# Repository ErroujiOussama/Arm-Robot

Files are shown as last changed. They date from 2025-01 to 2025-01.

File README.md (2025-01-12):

# Arm-Robot

## 3D Model

## Kinematics

## Hardaware

## Simulation 

### 1. PyBullet Robot Simulation

#### Overview
This Project provides a simulation setup using PyBullet to load and control a robot model.

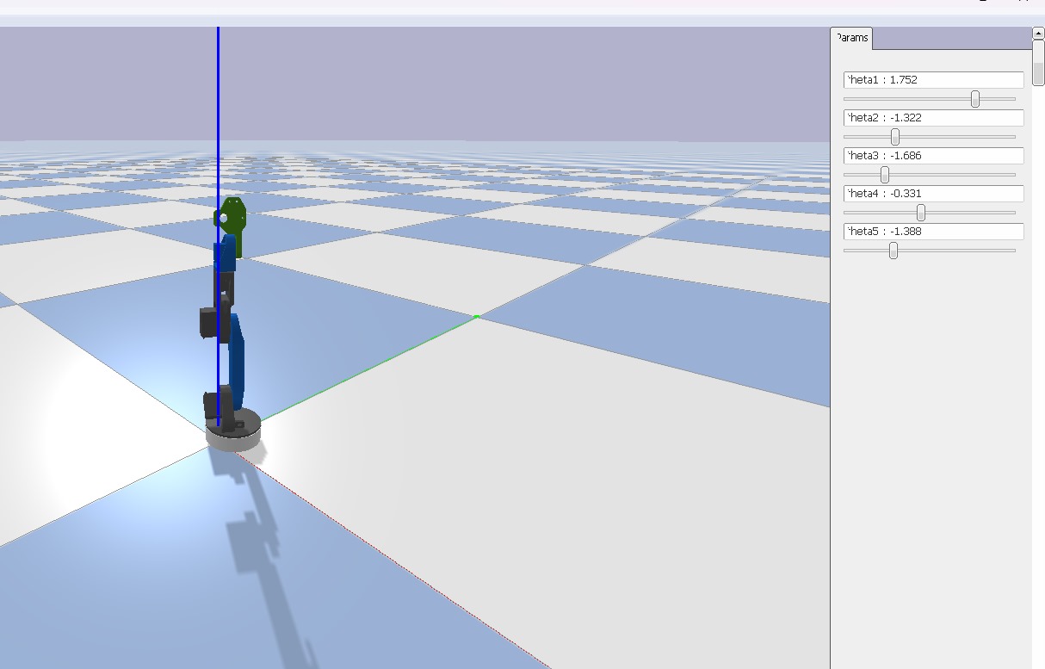
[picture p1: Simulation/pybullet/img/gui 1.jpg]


#### Features
- **Gravity and Physics Setup**: Configures gravity in the simulation.
- **Joint Control**: Creates sliders for each robot joint to control their positions interactively.

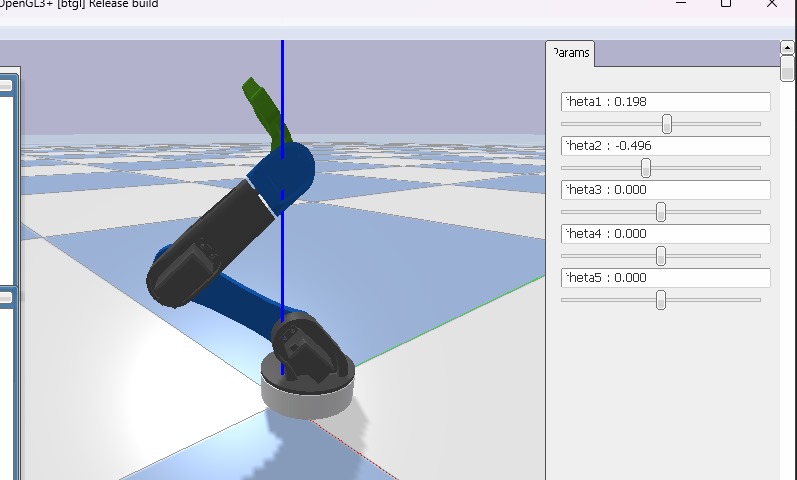
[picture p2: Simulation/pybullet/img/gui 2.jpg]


- **Collision Detection**: Detects and logs collisions between the robot's links and other objects in the environment.

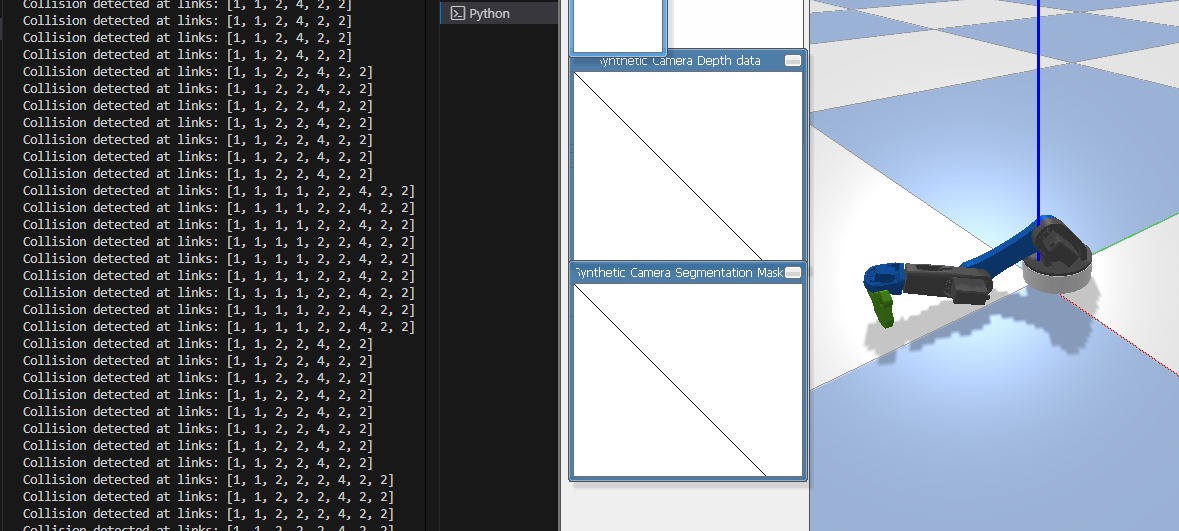
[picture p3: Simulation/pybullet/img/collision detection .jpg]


#### Notes
- The simulation runs at 240 Hz by default.

### 2. Roboticstoolbox (python)

This code combines simulation, kinematics, and control to visualize the motion of a robot arm.
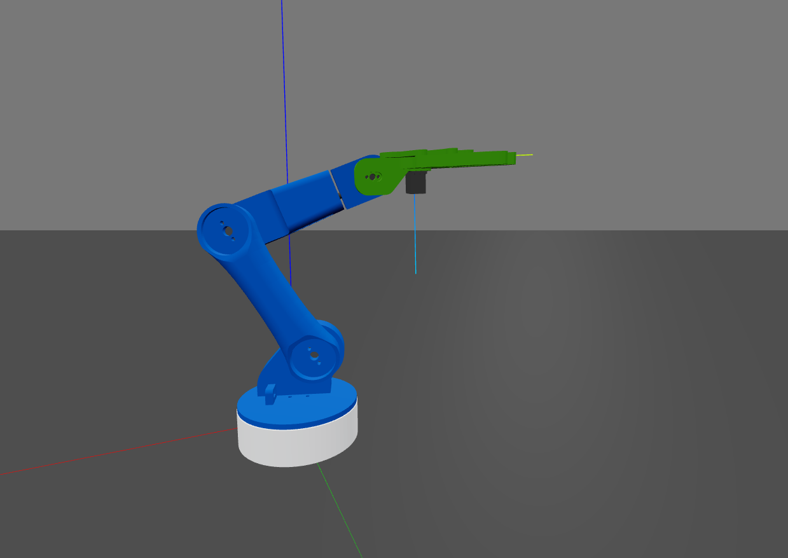
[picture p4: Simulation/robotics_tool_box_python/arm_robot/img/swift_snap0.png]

#### **Libraries and Tools**
- roboticstoolbox: Used for modeling and controlling robots.
- swift: Provides a 3D visualization interface for robotics simulation.
- spatialmath: Handles transformations like rotations and translations.
- spatialgeometry: Adds geometric primitives for visualization.

#### **Functions**
- move_to_position:
Moves the robot's end-effector to a target position using servoing.
Computes joint velocities using the Jacobian and pseudoinverse.

#### **Execution**
Sequential movements along the x, y, and z axes demonstrate the robot’s capability.

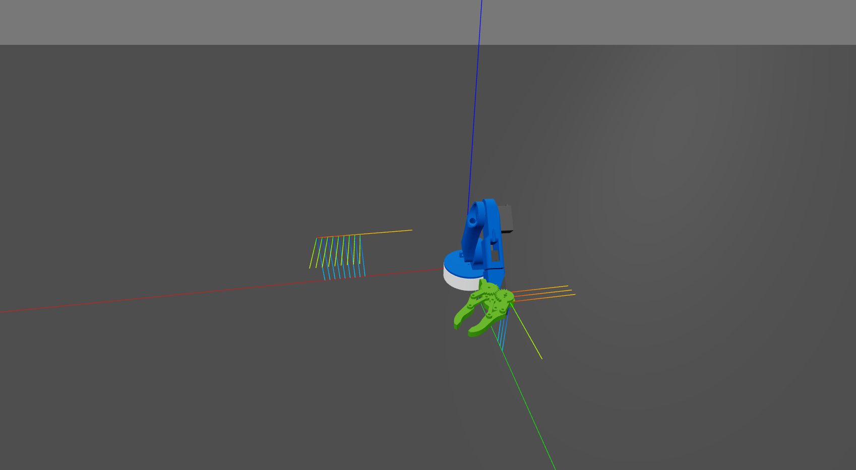
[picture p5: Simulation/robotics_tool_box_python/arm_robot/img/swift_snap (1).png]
 

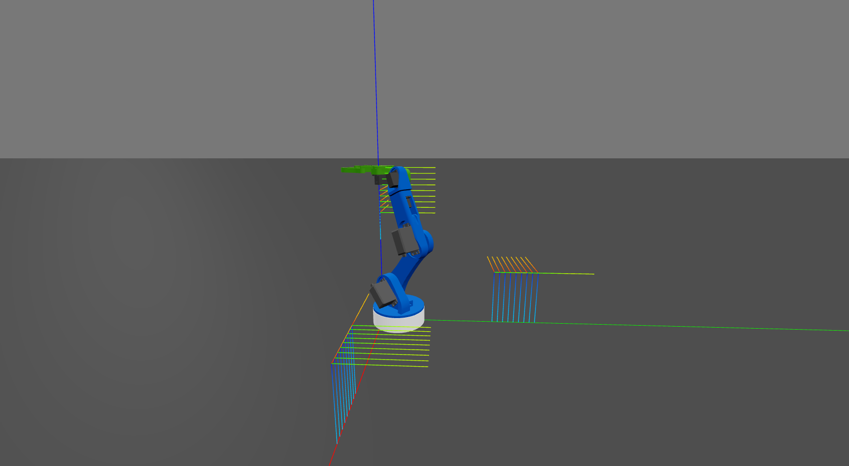
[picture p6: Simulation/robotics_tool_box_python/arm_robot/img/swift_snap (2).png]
 

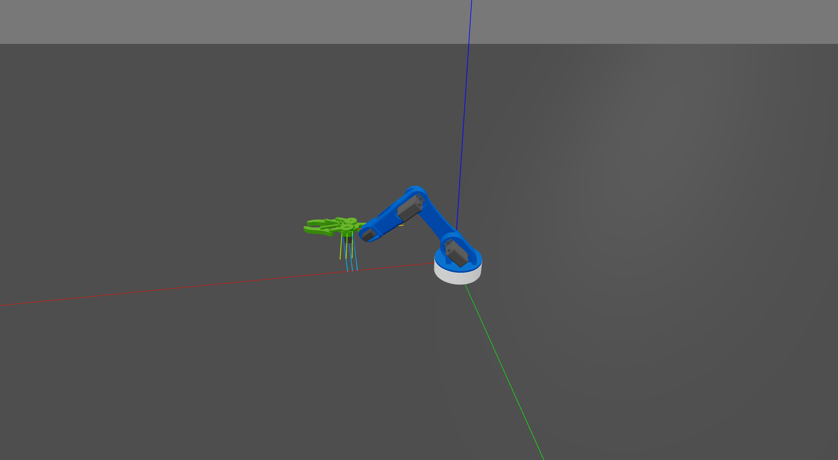
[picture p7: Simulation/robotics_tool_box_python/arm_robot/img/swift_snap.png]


#### **Details**:
##### **Servoing**:
Servoing is a feedback-based control technique that continuously adjusts the robot's motion to minimize the error between the current position (or pose) and the desired target position (or pose).
The function rtb.p_servo is used for position-based servoing.
- It calculates a velocity command v for the end-effector, based on the error between:
    
    - The current pose of the end-effector (from robot.fkine(robot.q)).
    
    - The target pose (Tep).
    
 - The gain parameter scales how aggressively the robot corrects the error.
 - The threshold parameter (set to 0.01) defines how close the end-effector must get to the target pose to consider the movement complete.

=> Servoing ensures that the end-effector dynamically adjusts its motion to precisely reach the target position.

##### **Jacobian Matrix (J)**
Maps joint velocities (`qd`) to end-effector velocity (`v`):
```
v = J * qd
```
##### **Pseudoinverse of Jacobian**
For non-square `J`, use the pseudoinverse (`J⁺`) to calculate `qd`:
```
qd = J⁺ * v
```
##### **In Code**
- `robot.jacobe(robot.q)`: Compute `J`.
- `np.linalg.pinv(J)`: Compute `J⁺`.
- `robot.qd = np.linalg.pinv(J) @ v`: Calculate `qd` for the desired `v`.

#### Dependencies
Ensure the following libraries are installed in your Python environment:
```
roboticstoolbox
swift
numpy 
spatialmath
spatialgeometry
```
#### Note
1- Update the paths in the URDF file to match your local system. For example:
```
<mesh filename="/Users/OUSSAMA/Desktop/projects/WIP/Arm robot project/5- simulation/robotics_tool_box_python/arm_robot/arm_01.stl"/>
```
2- Update the path in python coode:
```
robot = rtb.Robot.URDF("/Users/OUSSAMA/Desktop/projects/WIP/Arm robot project/5- simulation/robotics_tool_box_python/arm_robot/robot.urdf")
```

### 3. Simscape Robot Arm Control

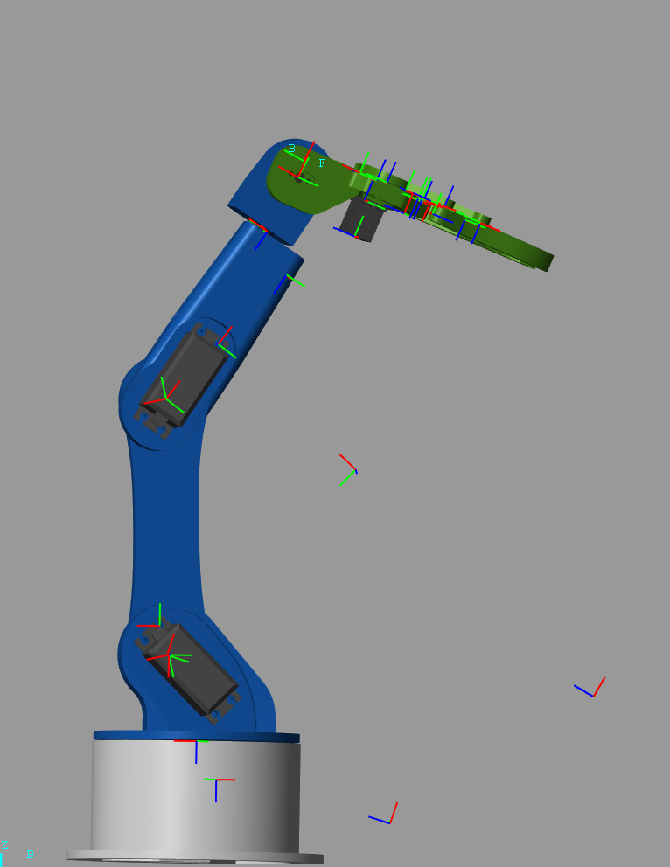
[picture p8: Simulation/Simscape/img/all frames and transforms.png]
 
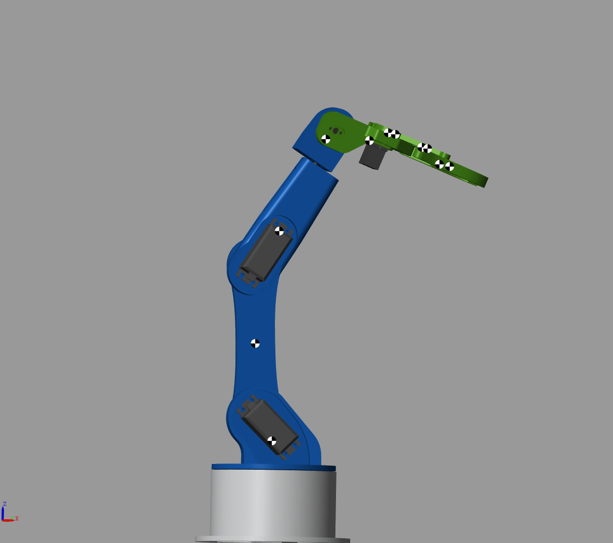
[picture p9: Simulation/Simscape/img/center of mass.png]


The model is structured as a **Rigid Body Tree**, which is subsequently transformed into a Simscape model. The Simscape model allows control over the arm's actuation through motion and torque inputs.

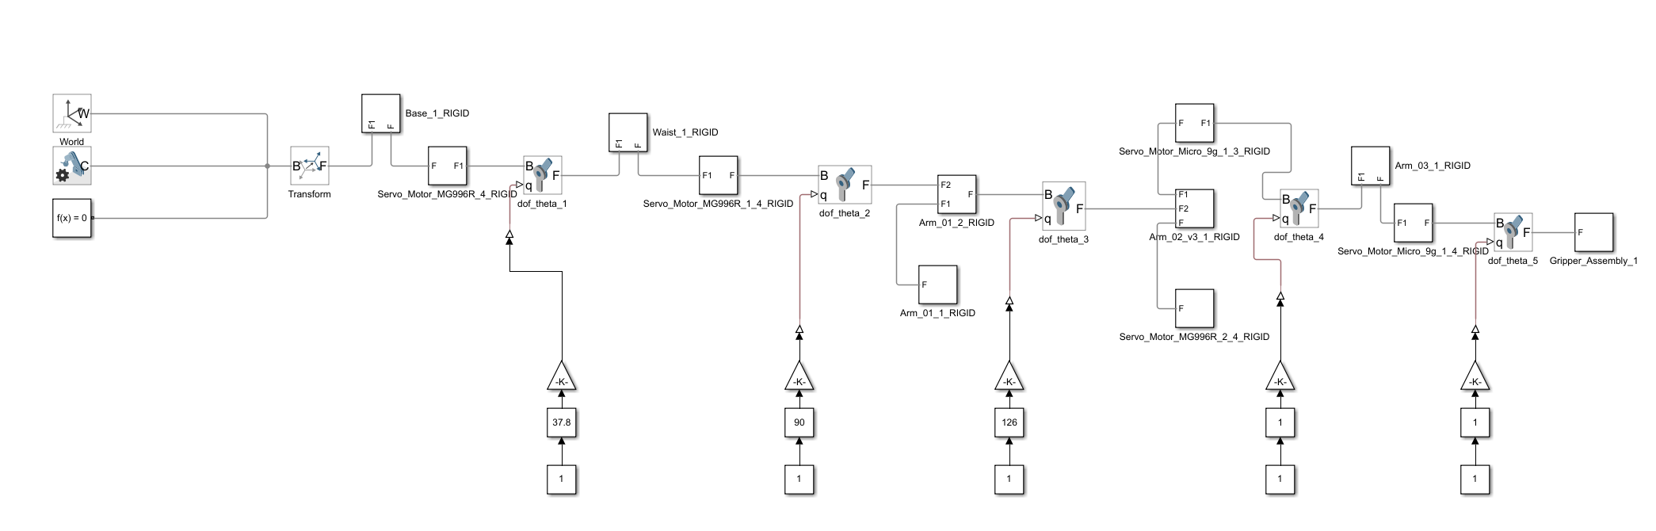
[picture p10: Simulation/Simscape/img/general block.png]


#### **Actuation Control**:
   - Control the motion and torque of the arm's joints.

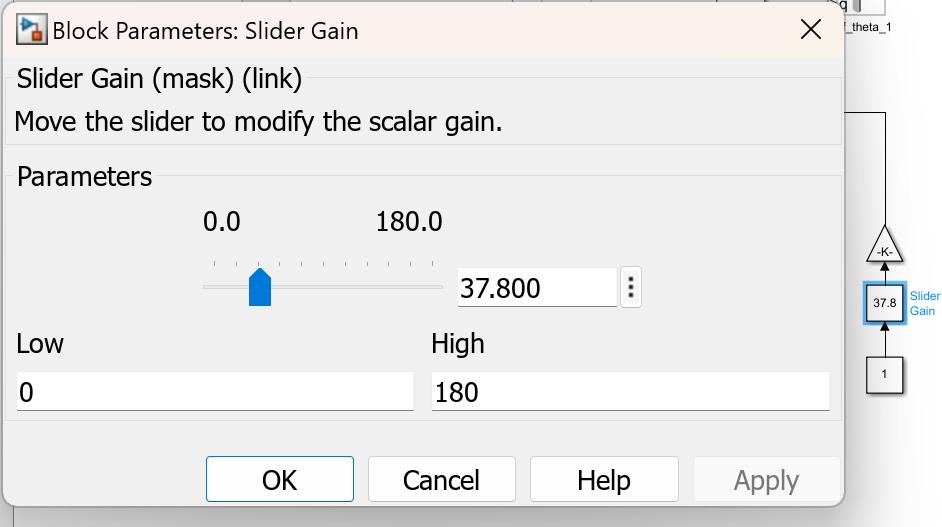
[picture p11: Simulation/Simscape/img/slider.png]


##### **Control System Design**:
   - **Low-Level Control**: Adjust motion inputs directly using sliders.
   - **High-Level Control**: Implement a PID controller to manage motion and torque inputs.

##### Low-Level Control (Motion Control)
- Use the slider blocks in Simulink to adjust the motion of individual joints.

##### High-Level Control (PID Control)
- Use the provided PID controller block to control both motion and torque.
- Adjust the PID parameters to optimize performance.

## Arduino Programming

## AI Model

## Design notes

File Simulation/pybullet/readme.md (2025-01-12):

# PyBullet Robot Simulation

## Overview
This Project provides a simulation setup using PyBullet to load and control a robot model.



## Features
- **Gravity and Physics Setup**: Configures gravity in the simulation.
- **Joint Control**: Creates sliders for each robot joint to control their positions interactively.



- **Collision Detection**: Detects and logs collisions between the robot's links and other objects in the environment.



## Notes
- The simulation runs at 240 Hz by default.

## License
This project is licensed under the وقف License. See https://ojuba.org/waqf-2.0 for details.

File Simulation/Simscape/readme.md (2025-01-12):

# Simscape Robot Arm Control Project

 


The model is structured as a **Rigid Body Tree**, which is subsequently transformed into a Simscape model. The Simscape model allows control over the arm's actuation through motion and torque inputs.



### **Actuation Control**:
   - Control the motion and torque of the arm's joints.



### **Control System Design**:
   - **Low-Level Control**: Adjust motion inputs directly using sliders.
   - **High-Level Control**: Implement a PID controller to manage motion and torque inputs.

#### Low-Level Control (Motion Control)
- Use the slider blocks in Simulink to adjust the motion of individual joints.

#### High-Level Control (PID Control)
- Use the provided PID controller block to control both motion and torque.
- Adjust the PID parameters to optimize performance.

## Future Work
- Extend the control system to support trajectory planning.
- Integrate ROS for real-time control and feedback.

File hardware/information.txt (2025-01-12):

* base : MG996R Servo
* Sholder : Arm 01 : MG996R servo
* Elbow : Arm02 : MG996R Servo
*wrist roll and wrist pitch : SG90S Servo Motor.
* Gripper : SG90 Servo

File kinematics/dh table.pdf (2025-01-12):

## Robotic Arm DH Parameters and Representation

Link Lengths

L0 = 9.525 cm,
L1 = 1.344 cm,
L2 = 12.000 cm,
L3 = 11.725 cm,
L4 = 12.200 cm.

Classic DH Table

i | αi | ai | di | θi
0 | 0 | 0 | 9.525 | θ1
1 | −π/2 | 1.344 | 0 | θ2 − 90◦
2 | 0 | 12.000 | 0 | θ3
3 | −π/2 | 0 | 11.725 | θ4
4 | π/2 | 0 | 0 | θ5
5 | −π/2 | 0 | 12.200 | 0

1

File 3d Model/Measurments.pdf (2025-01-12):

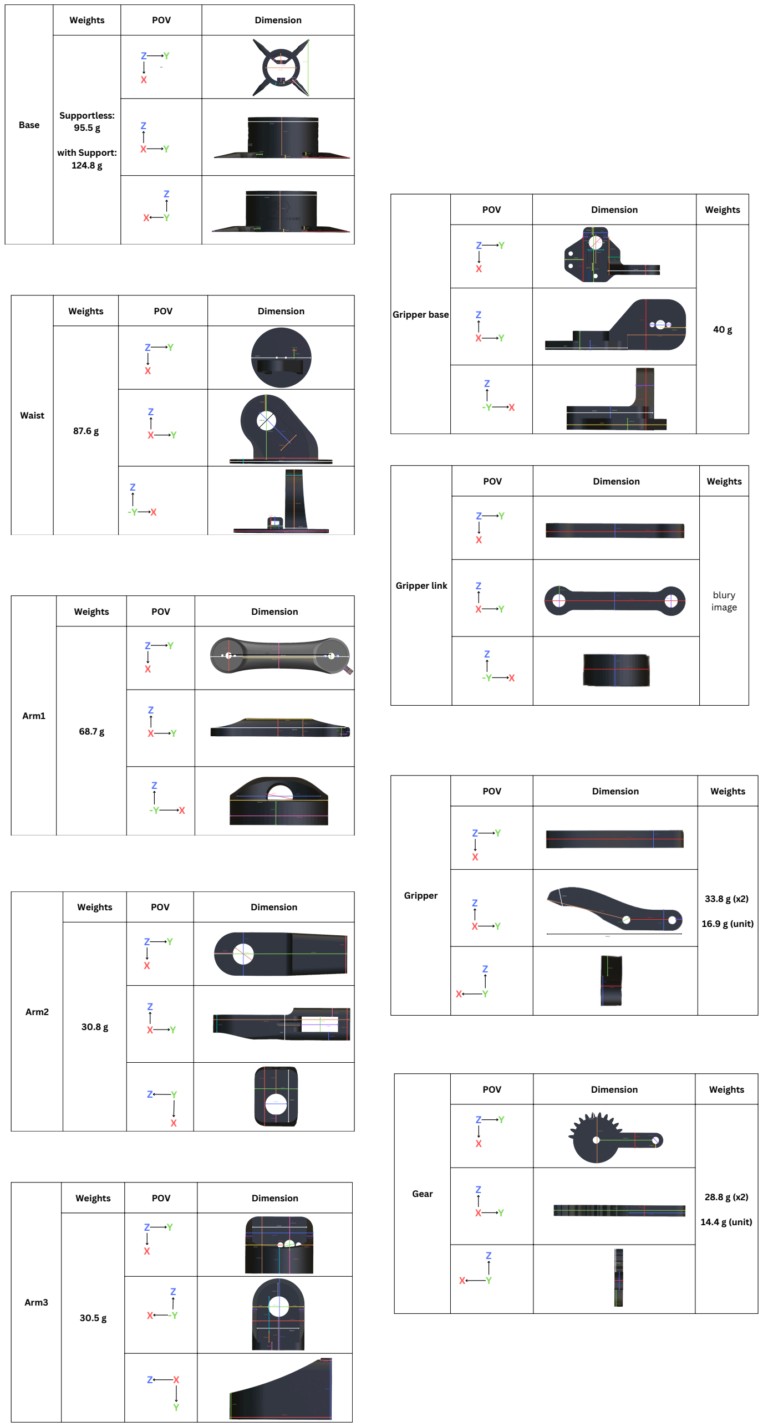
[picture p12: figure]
Arm3; Weights; POV; Dimension; Gear; 28.8 g (x2) 14.4 g (unit); Base; Waist; Arm1; Arm2; Gripper base; Gripper link; blury image; Gripper; 33.8 g (x2) 16.9 g (unit)

Supportless: 95.5 g with Support: 124.8 g | | 1.3 cm

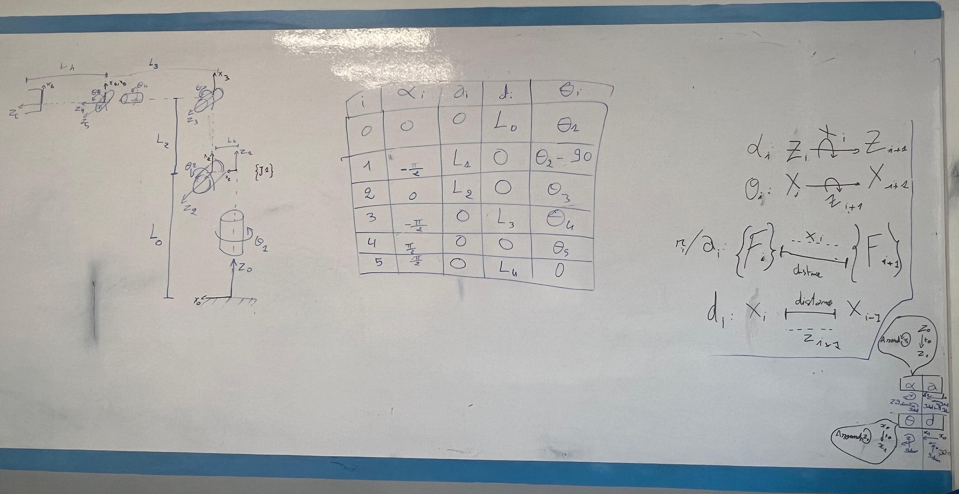
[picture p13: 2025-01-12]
kinematics/DH method white board.jpeg

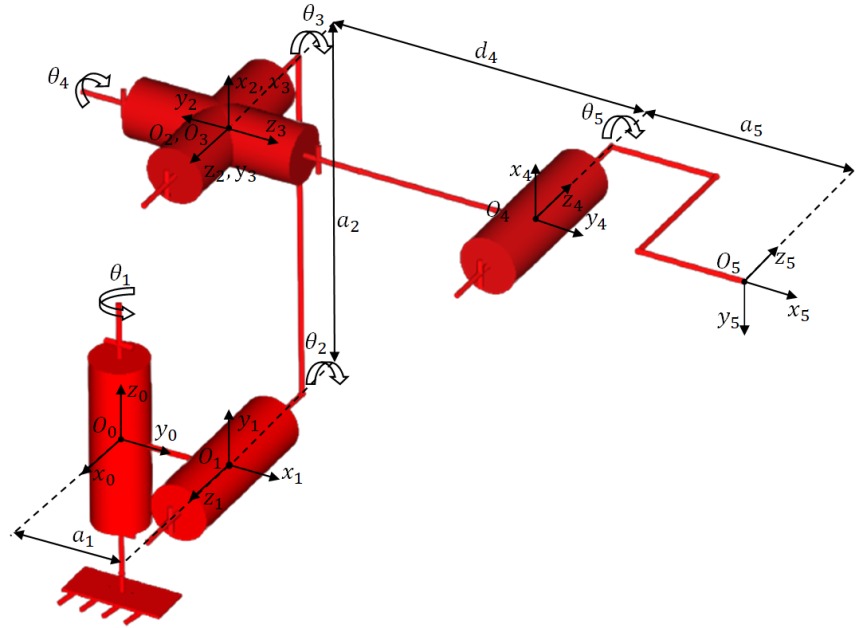
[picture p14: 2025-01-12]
kinematics/3d arm joints.jpeg

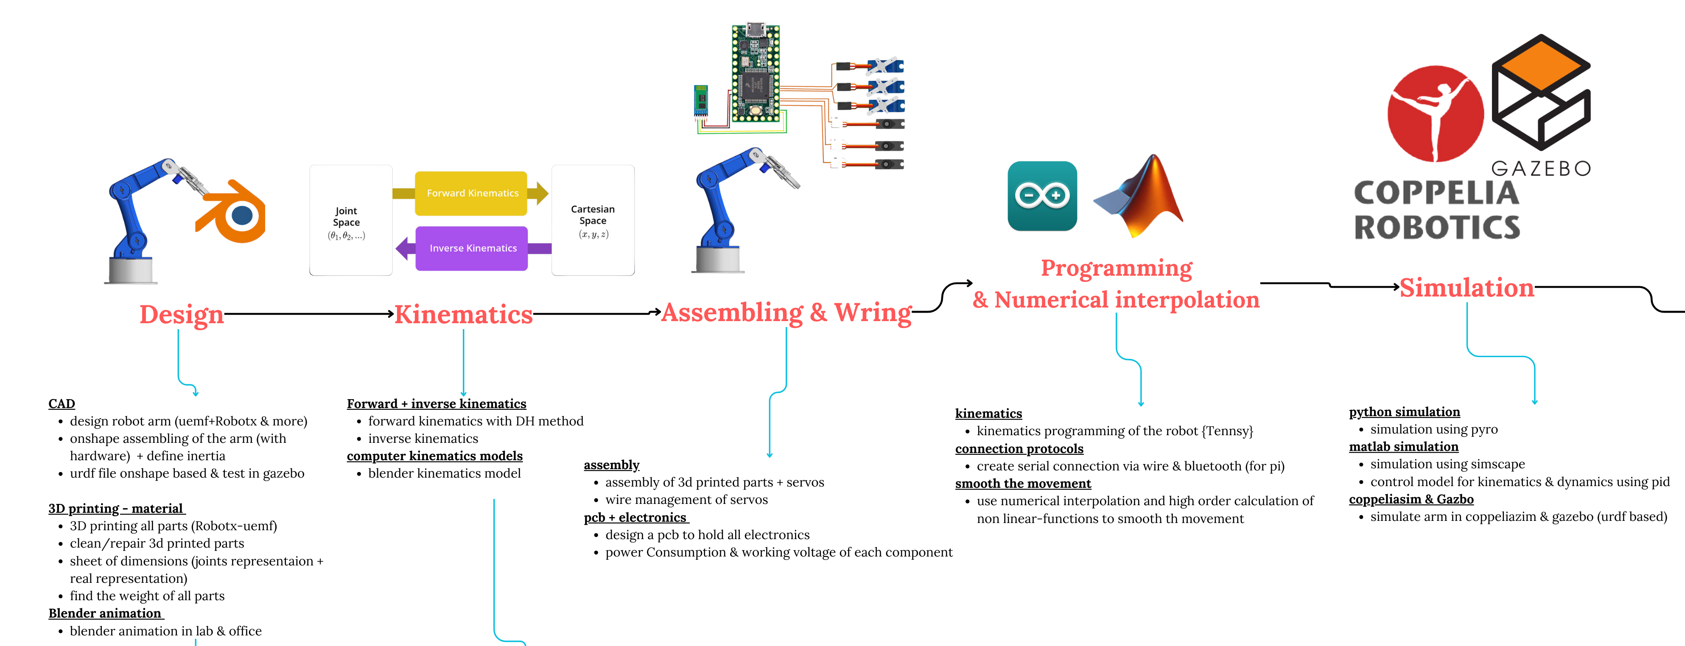
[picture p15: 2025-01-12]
img/mind map.png

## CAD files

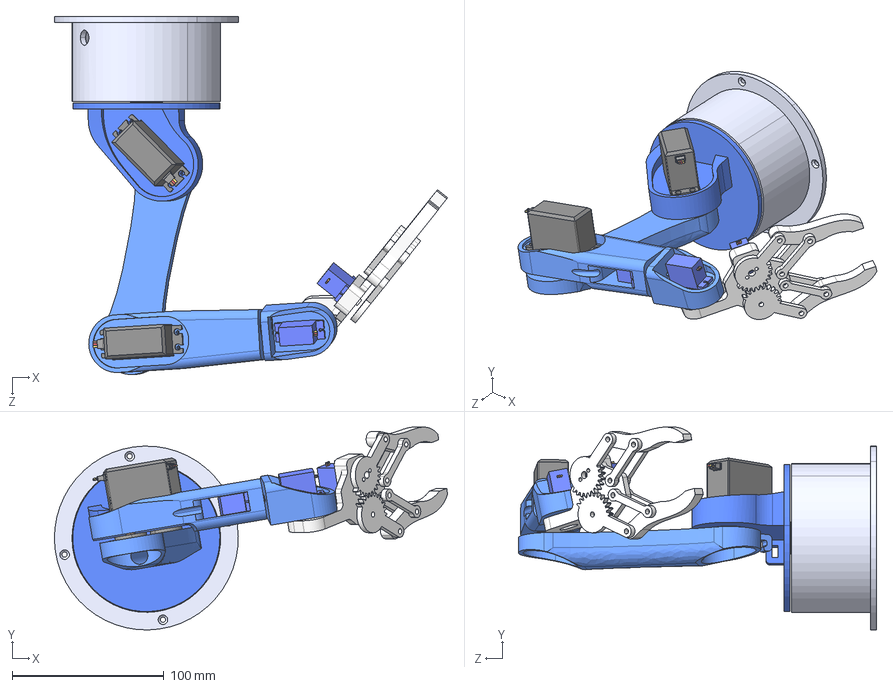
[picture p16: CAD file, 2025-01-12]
3d Model/3d model/Robotic Arm 3D Model.STEP
259.3 x 133.8 x 236.1 mm
Base
Servo Motor MG996R x 3
Waist
Arm 01
Servo Motor Micro 9g x 3
Arm 02 v3
Arm 03
gear1
gear2
grip link 1 x 4
Gripper base
Gripper 1 x 2

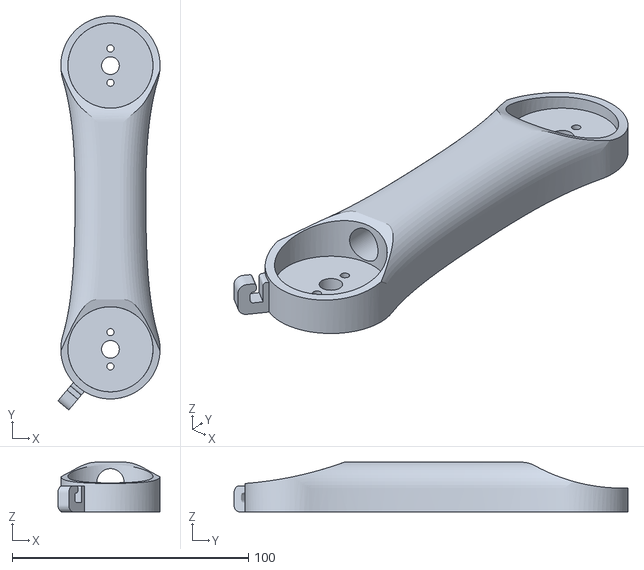
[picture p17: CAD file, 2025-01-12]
3d Model/3d model/STL/Arm 01.STL
43.2 x 166.7 x 21.0

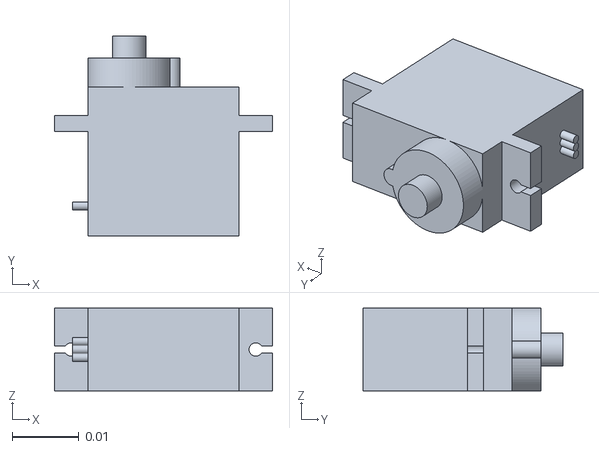
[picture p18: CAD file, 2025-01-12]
Simulation/pybullet/arm_robot_with_tool/servo_motor.stl
0.0326 x 0.0299 x 0.0124

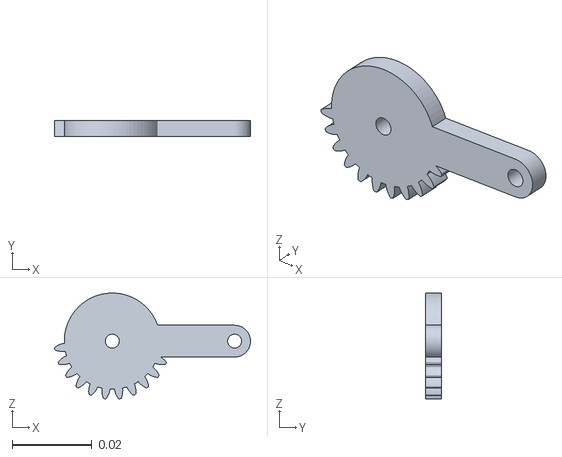
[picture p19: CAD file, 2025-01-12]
Simulation/robotics_tool_box_python/arm_robot/meshes/gear_1.stl
0.0493 x 0.004 x 0.0266

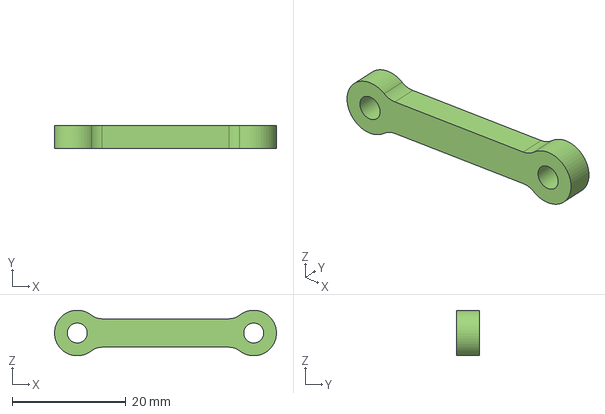
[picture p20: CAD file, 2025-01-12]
Simulation/Simscape/Grip Link.step
39.0 x 4.00 x 7.99 mm

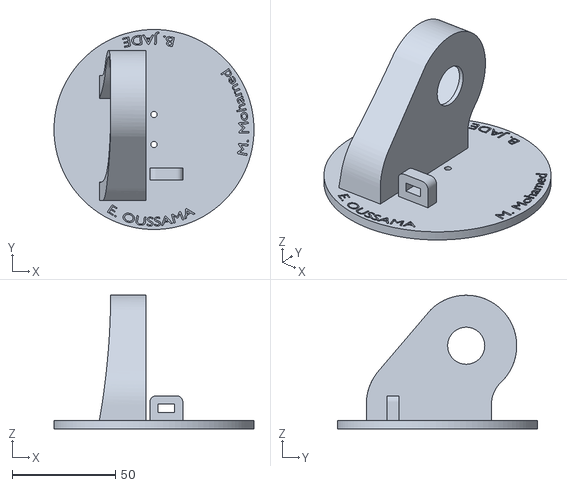
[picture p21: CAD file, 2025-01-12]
3d Model/3d model/STL/Project_Waist.stl
97.0 x 97.0 x 64.8

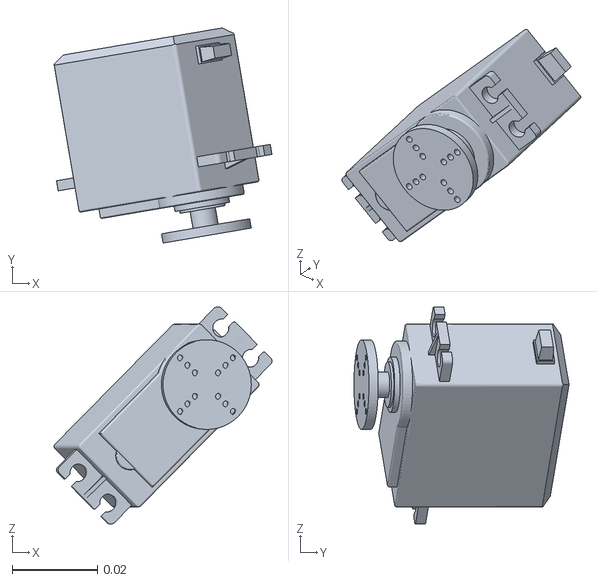
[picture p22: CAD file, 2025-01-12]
Simulation/pybullet/arm_robot_with_tool/servo_motor_mg996r_1.stl
0.0511 x 0.0504 x 0.0509

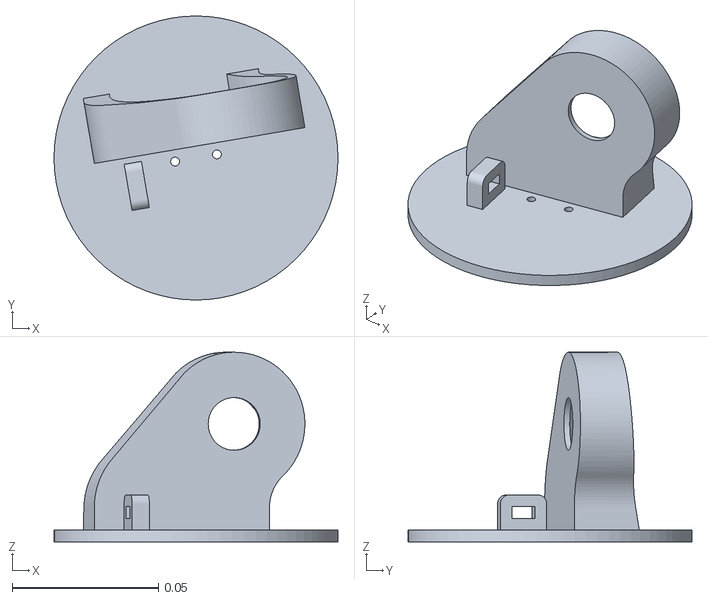
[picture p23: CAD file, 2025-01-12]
Simulation/robotics_tool_box_python/arm_robot/meshes/waist.stl
0.097 x 0.097 x 0.0648

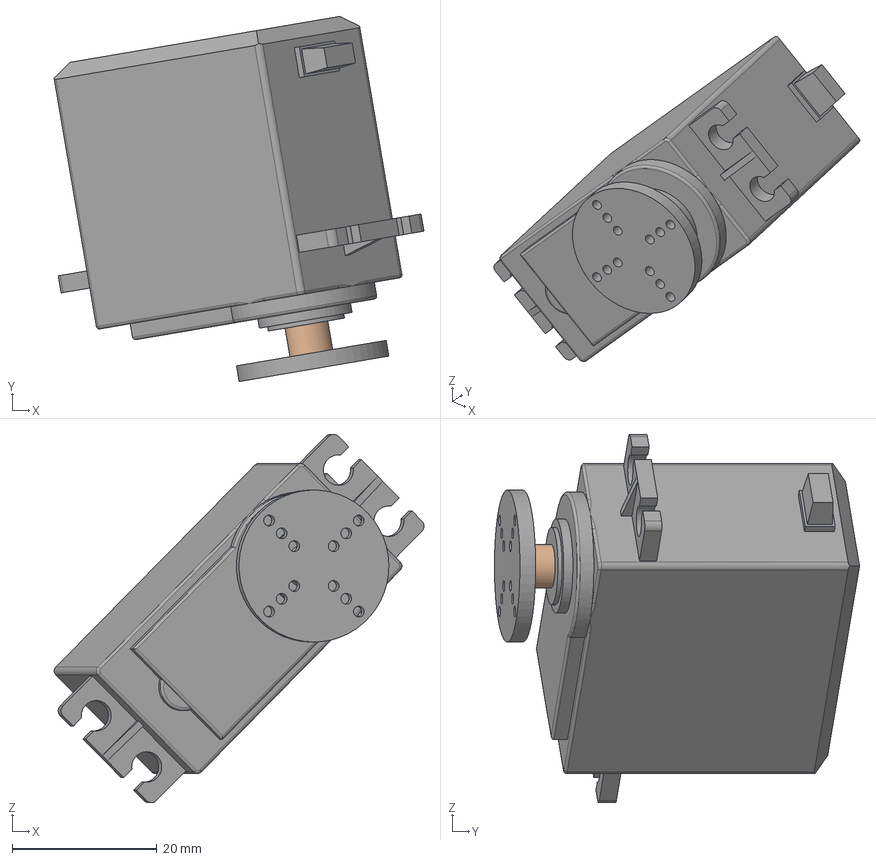
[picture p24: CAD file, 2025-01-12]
Simulation/Simscape/Servo Motor MG996R_1.step
51.1 x 50.4 x 50.9 mm

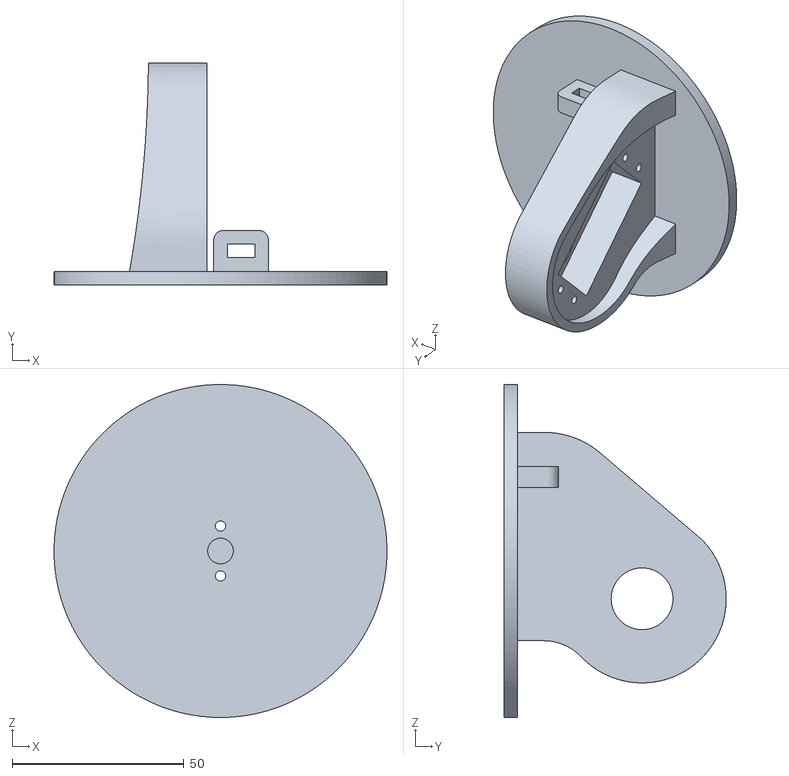
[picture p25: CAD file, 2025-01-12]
3d Model/3d model/STL/Waist.STL
97.0 x 64.8 x 97.0

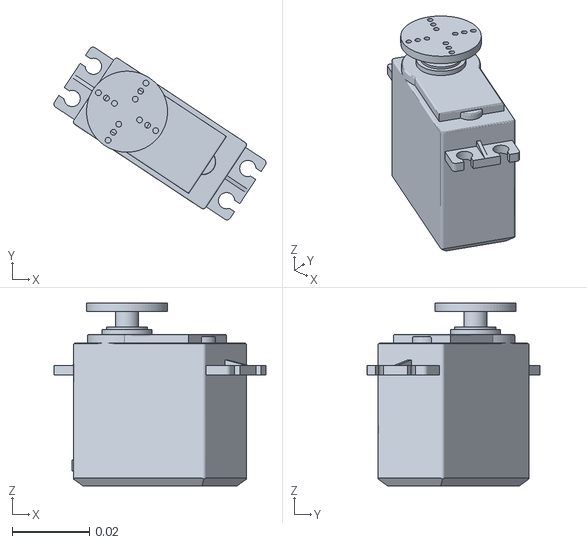
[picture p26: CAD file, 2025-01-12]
Simulation/robotics_tool_box_python/arm_robot/meshes/servo_motor_mg996r.stl
0.055 x 0.0448 x 0.0474

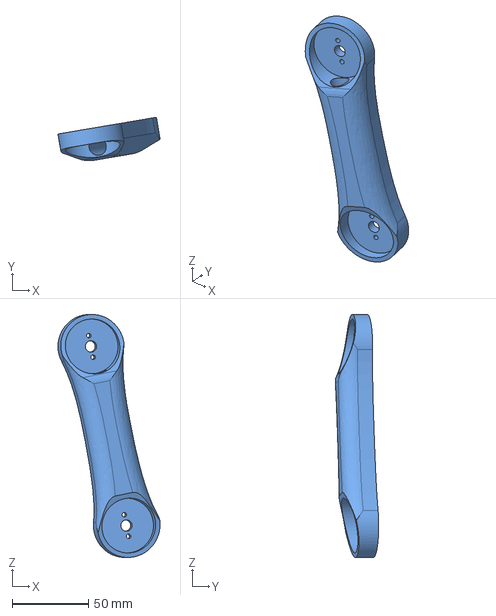
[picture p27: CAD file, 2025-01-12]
Simulation/Simscape/Arm 011.step
67.1 x 28.6 x 159.6 mm

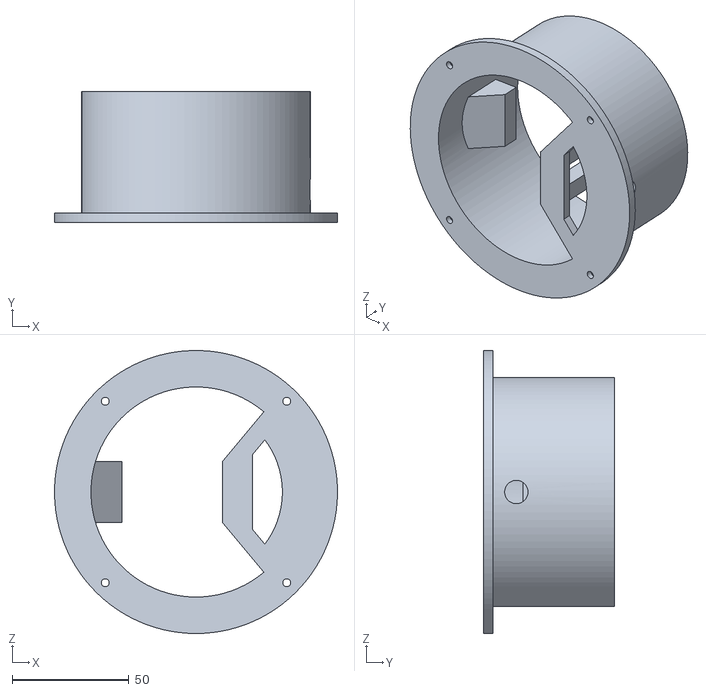
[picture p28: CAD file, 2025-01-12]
3d Model/3d model/STL/Base.STL
121.2 x 56.0 x 121.2

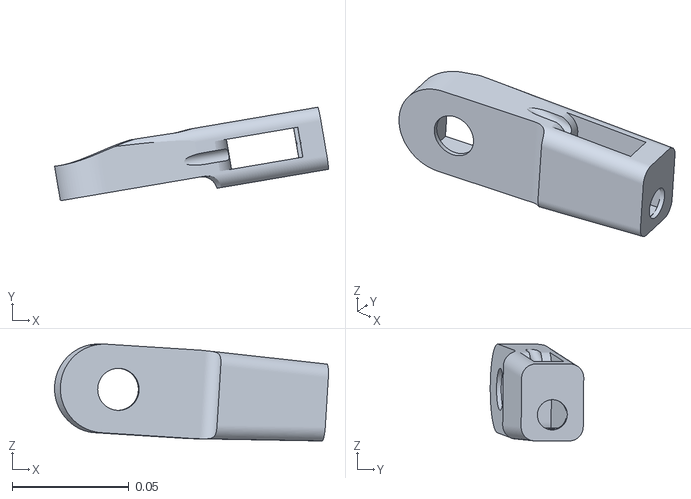
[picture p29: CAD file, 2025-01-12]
Simulation/pybullet/arm_robot_with_tool/arm_02_v3.stl
0.117 x 0.0401 x 0.0415

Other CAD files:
Simulation/pybullet/arm_robot_with_tool/gear_2.stl
Simulation/robotics_tool_box_python/arm_robot/meshes/gear_2.stl
Simulation/Simscape/Arm 03.step
3d Model/3d model/STL/Gripper base.STL
3d Model/3d model/STL/Arm 02 v3.STL
3d Model/3d model/STL/Arm 03.STL
3d Model/3d model/STL/Gripper 1.STL
3d Model/3d model/STL/gear1.STL
3d Model/3d model/STL/gear2.STL
3d Model/3d model/STL/grip link 1.STL
3d Model/3d model/STL/robotx_waist.stl
Simulation/Simscape/Arm 01.step
Simulation/Simscape/Arm 02 v3.step
Simulation/Simscape/Base.step
Simulation/Simscape/Gear 1.step
Simulation/Simscape/Gear 2.step
Simulation/Simscape/Gripper Base.step
Simulation/Simscape/Gripper.step
Simulation/Simscape/Servo Motor MG996R.step
Simulation/Simscape/Servo Motor MG996R_2.step
Simulation/Simscape/Servo Motor Micro 9g_1.step
Simulation/Simscape/Servo Motor.step
Simulation/Simscape/Waist.step
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

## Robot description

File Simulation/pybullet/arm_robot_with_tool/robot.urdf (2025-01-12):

<robot name="onshape">
<link name="base">
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
<inertial>
<origin xyz="0.002162793611686298495 0.031530345059669964702 -0.0055013484282212653936" rpy="0 0 0"/>
<mass value="5.0548333489920036499" />
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
</inertial>
</link>

<link name="waist">
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
<inertial>
<origin xyz="0.0009636382974727454977 -0.015447750665147899976 -0.023484589658302735399" rpy="0 0 0"/>
<mass value="0.14242800355200002649" />
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
</inertial>
</link>

<link name="link_1">
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
<inertial>
<origin xyz="-0.011676448687552519121 -0.056977296998755547208 -0.0077659352759508522984" rpy="0 0 0"/>
<mass value="0.068946039936000014237" />
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
</inertial>
</link>

<link name="link_2">
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
<inertial>
<origin xyz="0.025488788034272388816 -0.0016318541153327625112 -0.020131631218811722739" rpy="0 0 0"/>
<mass value="0.094800804912000019575" />
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
</inertial>
</link>

<link name="link_3">
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
<inertial>
<origin xyz="0.0056907977879946496091 0.0024069505050835532552 -0.019125435372435915099" rpy="0 0 0"/>
<mass value="0.039462536016000013261" />
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
</inertial>
</link>

<link name="gripper_base">
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
<inertial>
<origin xyz="0.0059759370980568479736 0.026335725347071306524 0.0017004909568270746342" rpy="0 0 0"/>
<mass value="0.039916128384000007512" />
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
</inertial>
</link>

<joint name="theta5" type="revolute">
<origin xyz="0.015684077597661424952 -0.0038009564709031856689 -0.028099990916539308028" rpy="1.5707963267944720087 1.569815992695214435 -2.1223603102889403438" />
<parent link="link_3" />
<child link="gripper_base" />
<axis xyz="0 0 1"/>
<limit effort="1" velocity="20" />
<joint_properties friction="0.0"/>
</joint>

<joint name="theta4" type="revolute">
<origin xyz="0.091100573746809188069 -0.010828478939053254315 -0.010729003761872498227" rpy="-1.570796326794906328 -0.6817127064207777476 1.5081084610459019046" />
<parent link="link_2" />
<child link="link_3" />
<axis xyz="0 0 1"/>
<limit effort="1" velocity="20" />
<joint_properties friction="0.0"/>
</joint>

<joint name="theta3" type="revolute">
<origin xyz="-0.023644920167362248886 -0.11764742984986586993 4.8572257327350598644e-17" rpy="3.1415926535897917837 -3.2423642731540817655e-15 2.5427429051385948" />
<parent link="link_1" />
<child link="link_2" />
<axis xyz="0 0 1"/>
<limit effort="1" velocity="20" />
<joint_properties friction="0.0"/>
</joint>

<joint name="theta2" type="revolute">
<origin xyz="0.013418564982389561205 -0.004111803921867322742 -0.040276480175933201955" rpy="-1.5707963267948958919 -1.4388195818050057984 2.9728608638233091632" />
<parent link="waist" />
<child link="link_1" />
<axis xyz="0 0 1"/>
<limit effort="1" velocity="20" />
<joint_properties friction="0.0"/>
</joint>

<joint name="theta1" type="revolute">
<origin xyz="0.0021709824683122797007 0.031524939536076955482 0.028716233202627644561" rpy="3.1415926535897917837 2.3186228305578418841e-15 -2.0901580159072090659" />
<parent link="base" />
<child link="waist" />
<axis xyz="0 0 1"/>
<limit effort="1" velocity="20" />
<joint_properties friction="0.0"/>
</joint>


</robot>

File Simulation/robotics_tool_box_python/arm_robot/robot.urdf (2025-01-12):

<robot name="onshape">
<link name="base">
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
<inertial>
<origin xyz="0.0021627936116862919898 0.031530345059669971641 -0.0055013484282212653936" rpy="0 0 0"/>
<mass value="5.0548333489920036499" />
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
</inertial>
</link>

<link name="waist">
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
<inertial>
<origin xyz="0.00096363829747273346306 -0.015447750665147920793 -0.023484589658302752746" rpy="0 0 0"/>
<mass value="0.14242800355199999873" />
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
</inertial>
</link>

<link name="link_1">
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
<inertial>
<origin xyz="-0.011676448687552557285 -0.056977296998755547208 -0.0077659352759508774519" rpy="0 0 0"/>
<mass value="0.068946039936000000359" />
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
</inertial>
</link>

<link name="link_2">
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
<inertial>
<origin xyz="0.025488788034272558819 -0.0016318541153328577041 -0.020131631218811719269" rpy="0 0 0"/>
<mass value="0.09480080491199999182" />
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
</inertial>
</link>

<link name="link_3">
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
<inertial>
<origin xyz="0.0056907977879946600175 0.0024069505050835515204 -0.019125435372435994896" rpy="0 0 0"/>
<mass value="0.0394625360160000202" />
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
</inertial>
</link>

<link name="gripper_base">
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
<inertial>
<origin xyz="0.0044916591755529483229 0.028495776208723615219 0.0038632963524563748541" rpy="0 0 0"/>
<mass value="0.048987975743999996603" />
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
</inertial>
</link>

<link name="gripper">
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
<inertial>
<origin xyz="-0.028564274528096442185 -0.020582360878763583667 0.00054120879120893869776" rpy="0 0 0"/>
<mass value="0.082553810975999980526" />
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
</inertial>
</link>

<joint name="gripper" type="revolute">
<origin xyz="0.01399999999999979039 0.037999999999999700684 0.017899999999999881284" rpy="1.570796326794896558 0.26179938779914885272 -1.5707963267948976682" />
<parent link="gripper_base" />
<child link="gripper" />
<axis xyz="0 0 1"/>
<limit effort="1" velocity="20" lower="-0.26179938779914940783" upper="0.785398163397448279"/>
<joint_properties friction="0.0"/>
</joint>

<joint name="theta5" type="revolute">
<origin xyz="0.015684077597661605363 -0.0038009564709030451563 -0.028099990916539308028" rpy="-1.5707963267948881203 1.5130053730197832174 1.0192323432971062136" />
<parent link="link_3" />
<child link="gripper_base" />
<axis xyz="0 0 1"/>
<limit effort="1" velocity="20" />
<joint_properties friction="0.0"/>
</joint>

<joint name="theta4" type="revolute">
<origin xyz="0.091100573746811241982 -0.010828478939054076574 -0.01072900376187257282" rpy="-1.5707963267949001107 -1.0035772518508432327 1.5081084610458845852" />
<parent link="link_2" />
<child link="link_3" />
<axis xyz="0 0 1"/>
<limit effort="1" velocity="20" />
<joint_properties friction="0.0"/>
</joint>

<joint name="theta3" type="revolute">
<origin xyz="-0.023644920167362300928 -0.1176474298498657034 1.0755285551056203985e-16" rpy="-3.1415926535897913396 -2.0535690044882846071e-15 -1.7166171415890869589" />
<parent link="link_1" />
<child link="link_2" />
<axis xyz="0 0 1"/>
<limit effort="1" velocity="20" />
<joint_properties friction="0.0"/>
</joint>

<joint name="theta2" type="revolute">
<origin xyz="0.013418564982389535184 -0.0041118039218674649893 -0.040276480175933174199" rpy="1.570796326794896558 -0.26810859151204358142 -0.16873178976647065785" />
<parent link="waist" />
<child link="link_1" />
<axis xyz="0 0 1"/>
<limit effort="1" velocity="20" />
<joint_properties friction="0.0"/>
</joint>

<joint name="theta1" type="revolute">
<origin xyz="0.0021709824683122797007 0.031524939536077073443 0.02871623320262758905" rpy="-3.1415926535897908956 -2.3846145207440365311e-15 0.71119967984597842747" />
<parent link="base" />
<child link="waist" />
<axis xyz="0 0 1"/>
<limit effort="1" velocity="20" />
<joint_properties friction="0.0"/>
</joint>


</robot>

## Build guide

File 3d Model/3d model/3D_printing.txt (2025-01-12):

============= Mechanical Components =====================
	
	- Arm01 .
	- Arm02 .
	- Arm03 .
	- Base .
	- Gear1 .
	- Gera2 .
	- Grip link . ( ×4 pieces ) 
	- Gripper . ( ×2 pieces )
	- Gripper base .
	-Waist

================ Caracteristics & Specs======================
	
	- 0.2mm layer height.  (la couche )
	- 40% infill ( remplissage )
	- 200 degrees nozzle tepm for a normal PLA material.
	- Orange color : arm1,arm2,arm3,waist.
	-White color : Base,gripper,grip link,gear1,gear2.
	
========================================================

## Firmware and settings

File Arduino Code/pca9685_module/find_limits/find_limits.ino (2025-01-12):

#include <Adafruit_PWMServoDriver.h>
Adafruit_PWMServoDriver pca = Adafruit_PWMServoDriver(0x40);       // called this way, it uses the default address 0x40   


int ServoPins[]={0,1,2,4,6,8};

short SERVOMIN[]={125,125,125};
short SERVOMAX[]={620,400,620};

enum Servo_Type{
  sg90 = 1,
  mg90s = 2,
  mg996r = 3
};

void setup() {
  Serial.begin(9600);
  Serial.println("Start!");
  pca.begin();
  pca.setPWMFreq(60);                  // Analog servos run at ~60 Hz updates
}


void loop() 
  {  
  //  for(int i : ServoPins){
  //  Set_To_Zero(0);
  //  }
 ;
  
  
  Set_To_Meduim(0);
  delay(2000);

  
  Set_To_Meduim(1);
  Set_To_Meduim(2);
  delay(2000);
  Set_To_Max(1);
  Set_To_Max(2);
  delay(2000);
  Set_To_Zero(1);
  Set_To_Zero(2);
  delay(2000);

  }

//coversion
int angleToPulse(int ang,int Servo_num)                             //gets angle in degree and returns the pulse width
  {  int pulse = map(ang,0, 180, SERVOMIN[Servo_num],SERVOMAX[Servo_num]);  // map angle of 0 to 180 to Servo min and Servo max 
     Serial.print("Angle: ");Serial.print(ang);
     Serial.print(" pulse: ");Serial.println(pulse);
     return pulse;
  }

//SET
void Set_To_Zero(int Servo_num){
 int angle = 0;
 pca.setPWM(Servo_num, 0, angleToPulse(angle,Servo_num));
}

void Set_To_Max(int Servo_num){
  int angle = 179;
  pca.setPWM(Servo_num, 0, angleToPulse(angle,Servo_num));
}

void Set_To_Meduim(int Servo_num){
  int angle = 90;
  pca.setPWM(Servo_num, 0, angleToPulse(angle,Servo_num));
}

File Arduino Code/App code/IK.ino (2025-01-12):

#include <Servo.h>

int ServoPins[] = {3, 5, 6, 9, 10, 11};
Servo Servos[6];
String inputString = "";
int servoAngles[6];

void setup() {
  Serial.begin(9600);
  for (int i = 0; i < 6; i++) {
    Servos[i].attach(ServoPins[i]);
    servoAngles[i] = 90; // Default position
    Servos[i].write(servoAngles[i]);
  }
}

void loop() {
  if (Serial.available()) {
    char inChar = (char)Serial.read();
    if (inChar == '\n') {
      parseData();
    } else {
      inputString += inChar;
    }
  }
}

void parseData() {
  int index = 0;
  char *token = strtok((char *)inputString.c_str(), ",");
  while (token != NULL && index < 6) {
    servoAngles[index] = constrain(atoi(token), 0, 180);
    Servos[index].write(servoAngles[index]);
    token = strtok(NULL, ",");
    index++;
  }
  inputString = "";
}

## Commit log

2025-01-12 add simulation
    [Arm 01.step, Arm 011.step, Arm 02 v3.step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]
2025-01-12 3d model
    [Arm 01.STL, Arm 02 v3.STL, Arm 03.STL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]
